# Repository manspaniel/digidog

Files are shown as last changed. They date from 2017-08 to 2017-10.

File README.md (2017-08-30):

# Digi-Dog

Lil digital dog for your pocket, for when you can't have a real dog (or when your real dog doesn't fit in your pocket).

## Work in Progress!

This project isn't finished yet! There's still plenty to do, but the basics are all there.

## PCB Files

Eagle files are provided in the `pcb` folder. I print the circuit board layout onto transparent A4 overhead projector material, then use pre-sensitised PCB boards + developer + chemical etchant to produce the boards. Watch [this video](https://www.youtube.com/watch?v=tWnfnt2rNO0) for the process I follow. It's easy once you have the stuff :)

This is my first PCB design. The layout is a bit shit, but that's ok.

## Uploading

I'm using Platform IO to manage platforms/libraries, and to upload compiled code to the ATTiny85. To program the chip, I'm using [https://www.sparkfun.com/products/11801](SparkFun Tiny Programmer), which is just great; you can program on the chip, or use breakout wires to program onto your soldered prototype. (I've added a breakout header row to my PCB for connecting the microcontroller to the programmer via some breadboard jumper wires).

## Tools

Comes with a custom-made sprite drawing program. To use:

```bash
> cd tools/sprite-draw
> npm install
> npm start
```

Documentation for the sprite drawing tool is [here](./tools/sprite-draw/README.md).

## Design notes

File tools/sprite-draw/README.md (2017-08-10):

Dog Editor
==========

A quick and hacky tile-based bitmap editor, specifically built for the purpose
of creating virtual pet dog sprites and related imagery.

## Running the tool

You'll need Node JS 8 or higher installed for this tool to work.

After you've cloned the project repository, cd into the dog editor folder, and start her up!

```bash
> cd tools/dog-editor
> npm install
> npm start
```

## Tile system

The system uses a tile system.

A **tileset** is a group of 64 tiles. Tilesets are all stored together, however they are paged in chunks of 64 to reduce the size of the sprites themselves, while expanding the amount of tiles that can be used by the program.

A **tiles** is an 8x8 monochrome bitmap. Each column (or row) can be represented in 1 byte (8 bits), since there are only two possible values for each pixel — black or white. This means each tile takes up 8 bytes in total.

A **sprite** (probably poorly named) has a variable width and height, and is composed entirely of tiles. A sprite must also reference a single **tileset**, which means that no sprite can use tiles from two different tilesets.

Tilesets are in groups of 64, because it means that each tile within a sprite can be referenced with only one byte. Two bits of each sprite tile each is reserved for flipX and flipY, and the remaining 6 bits can be used to reference a tile. The tileset number attached to the sprite just provides the pagination value.

## Loading and Saving

Hit the "Save" button to persist your tiles and sprites to disk.

Hit the "Reload" button to reload the persisted data.

Hit the "Publish Headers" button to generate and publish the `tiles.h` file to the parent project (ie. `../../src/tiles.h`).

## Persisting to a different file

All data is persisted in a JSON file, which by default is `data.json` within the dog-editor project folder. When booting the server app, you can actually specify another file using:

```bash
> npm start -- doggytest.json
```

## Tips and Functions

In the "Tiles" section:

* Drag with the mouse from one tile to another to copy sprite data!
* Do the same while holding SHIFT to *swap* those tiles. Sprites using either of those tiles will also be updated to point to the swapped tile, so your tiles wont break. This is really useful for organising your tileset.
* Clicking on a tile will highlight in green any sprite which uses that tile. This is good for determining if a tile is actually in use by any sprite.

In the sprite editor:

* Tools are represented by letters. You can press that letter on your keyboard to activate the tool!
* Some tools do something different when you right click.
  * The pencil tool (P) draws white by default, and erases to black with right mouse button.
  * The tile tool (T) draws the selected tile, but if you right click on a tile in your active sprite it acts as an eye dropper!

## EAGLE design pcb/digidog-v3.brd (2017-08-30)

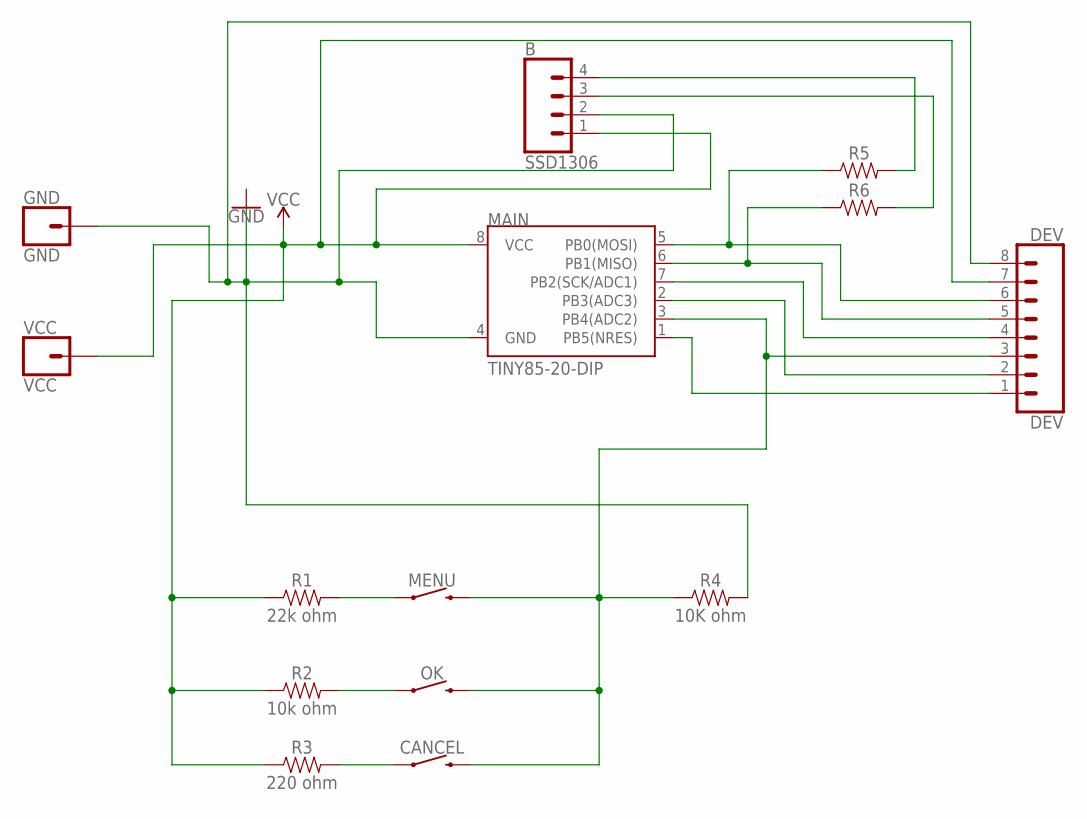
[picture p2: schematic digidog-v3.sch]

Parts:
B: SSD1306; 1X04
CANCEL: MOMENTARY-SWITCH-SPST-PTH-6.0MM; TACTILE_SWITCH_PTH_6.0MM
DEV: DEV; 1X08
GND: GND; 1X01
MAIN: TINY85-20-DIP; DIP08_MCU
MENU: MOMENTARY-SWITCH-SPST-PTH-6.0MM; TACTILE_SWITCH_PTH_6.0MM
OK: MOMENTARY-SWITCH-SPST-PTH-6.0MM; TACTILE_SWITCH_PTH_6.0MM
R1: 22k ohm; AXIAL-0.3
R2: 10k ohm; AXIAL-0.3
R3: 220 ohm; AXIAL-0.3
R4: 10K ohm; AXIAL-0.3
R5, R6: AXIAL-0.3
VCC: VCC; 1X01

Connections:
BUTTON: CANCEL.3 (2), DEV.3, MAIN.3 (PB4(ADC2)), MENU.3 (2), OK.3 (2), R4.P$1 (1)
GND: B.2, DEV.8, GND.1, MAIN.4 (GND), R4.P$2 (2)
unnamed: B.4, R5.P$2 (2)
unnamed: MENU.1, R1.P$2 (2)
unnamed: OK.1, R2.P$2 (2)
unnamed: CANCEL.1, R3.P$2 (2)
unnamed: DEV.6, MAIN.5 (PB0(MOSI)), R5.P$1 (1)
unnamed: DEV.5, MAIN.6 (PB1(MISO)), R6.P$1 (1)
unnamed: B.3, R6.P$2 (2)
unnamed: DEV.1, MAIN.1 (PB5(NRES))
unnamed: DEV.2, MAIN.2 (PB3(ADC3))
unnamed: DEV.4, MAIN.7 (PB2(SCK/ADC1))
VCC: B.1, DEV.7, MAIN.8 (VCC), R1.P$1 (1), R2.P$1 (1), R3.P$1 (1), VCC.1

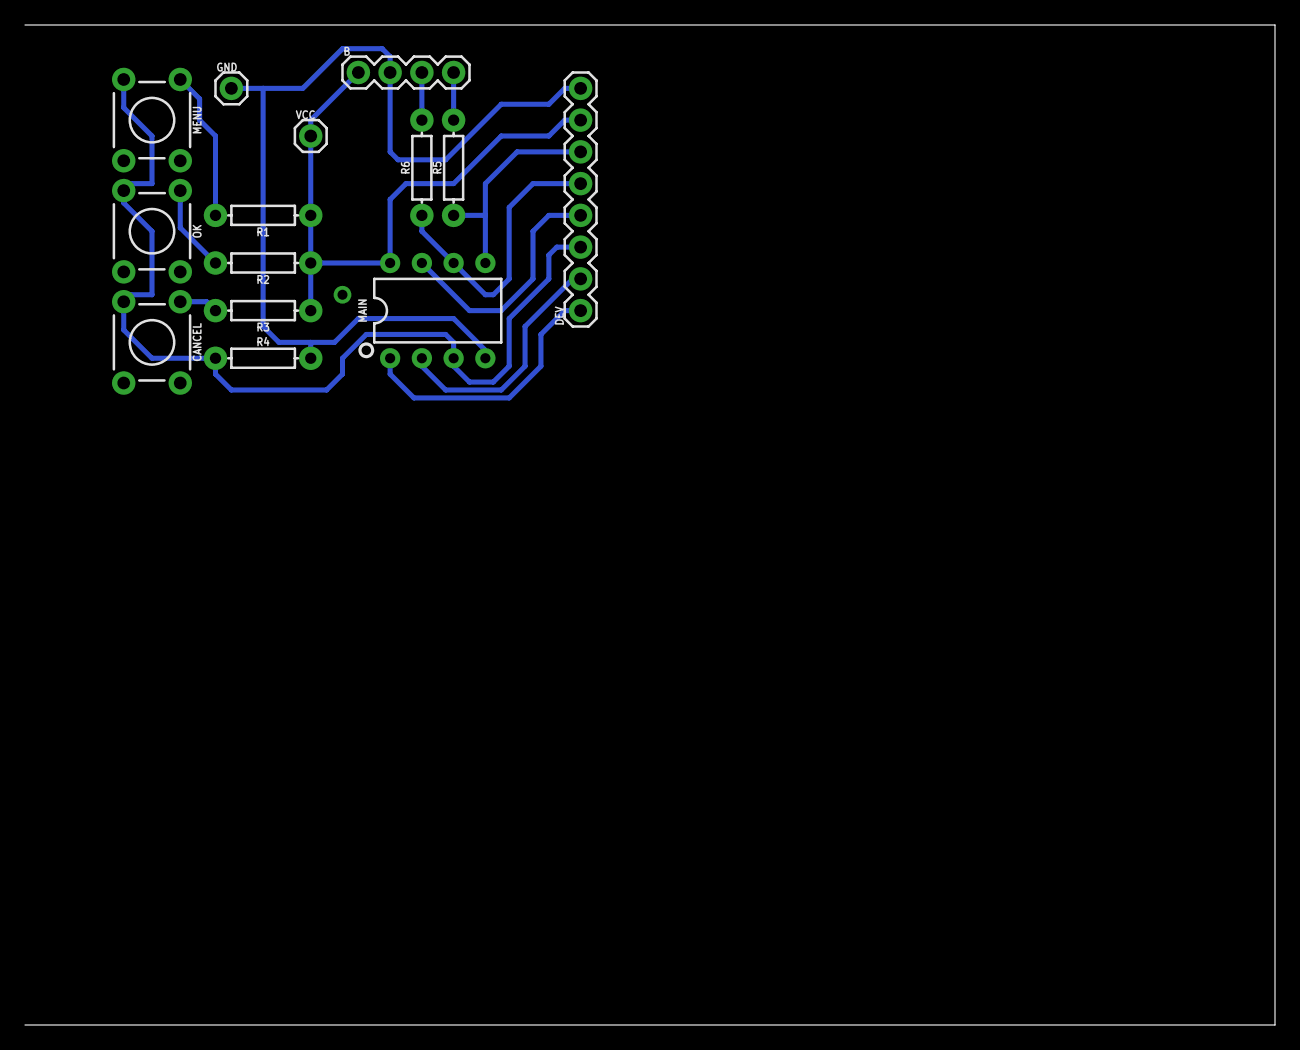
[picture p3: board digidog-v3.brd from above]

Board: 2 copper layers, 100.0 x 80.0 mm, 14 parts (0 on the bottom side), 13 nets.

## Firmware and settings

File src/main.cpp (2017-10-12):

#include <Arduino.h>
// #define F_CPU 8000000UL      //ATtiny85 CPU Clock speed (8MHz optimal[8000000], 1MHz Default[1000000])

#define SSD1306_SA    0x78  // Slave address

// #include <stdlib.h>
// #include <avr/io.h>
// #include <util/delay.h>
// #include <avr/pgmspace.h>
// #include <avr/sleep.h>

#include "ssd1306xled.h"
#include "DigiDog.h"
#include "SpriteDisplay.h"

// void * operator new(size_t size) {
//   return malloc(size);
// }
//
// void operator delete(void * ptr) {
//   free(ptr);
// }

// #define CALIBRATON_MODE true

#ifndef CALIBRATON_MODE
  SpriteDisplay mainDisplay;
  DigiDog doggy;
#endif

void setup() {
  // Small delay is necessary if ssd1306_initis the first operation in the application.
  // _delay_ms(40);
  ssd1306_init();
 
  ssd1306_fillscreen(0x0);
  // ssd1306_char_f8x16(1, 2, "VDOG");
  delay(100);
 
  // set_sleep_mode(SLEEP_MODE_PWR_DOWN);
  // setup_watchdog(6);
 
  // uint8_t p = 0xff;
 
  // for (uint8_t i = 0; i < 4; i++) {
  //   p = (p >> i);
  //   ssd1306_fillscreen(~p);
  //   _delay_ms(200);
  // }
  
  // pinMode(A2, INPUT);
  
  #ifndef CALIBRATON_MODE
    doggy.start();
  #endif
  
}

void loop() {
  
  // Figure out the current button
  
  #ifdef CALIBRATON_MODE
    int signal = analogRead(A2);
    
    ssd1306_fill_range(0, 60, 0x00);
    char buffer[10];         //the ASCII of the integer will be stored in this char array
    itoa(signal, buffer, 10);
    ssd1306_char_f6x8(0, 0, buffer);
  #endif
  
  #ifndef CALIBRATON_MODE
    doggy.loop();
  #endif
  
  // delay(100);
  
  // watchdog_counter = analogRead(A2);
  //
  // ssd1306_fill_range(0, 60, 0x00);
  // char buffer[10];         //the ASCII of the integer will be stored in this char array
  // itoa(val, buffer, 10);
  // ssd1306_char_f6x8(0, 0, buffer);
  
  // setup_watchdog(8);
  // sleep_mode();
  
  
  
  // ssd1306_send_byte(252);
 
  // ssd1306_char_f6x8(1, 0, "Who says I can't run this LED screen?");
  // _delay_ms(5000);
  //
  //
  // ssd1306_char_f6x8(1, 0, "There am I running it now.");
  // _delay_ms(5000);
 
}

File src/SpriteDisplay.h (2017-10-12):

#ifndef SPRITE_DISPLAYM_H
#define SPRITE_DISPLAYM_H

#include <stdlib.h>
#include <avr/io.h>
#include <avr/pgmspace.h>
#include "ssd1306xled.h"
#include "tiles.h"
#include "font6x8.h"

#define MAX_SPRITES               16
#define SPRITE_HEADER_SIZE        3

class SpriteDisplay;

struct Sprite {
  const uint8_t * data;
  bool active = false;
  uint8_t tileset = 0;
  uint8_t x = 0;
  uint8_t y = 0;
  uint8_t width = 0;
  uint8_t height = 0;
  char cols = 0;
  char rows = 0;
  
  uint8_t lastX = 0;
  uint8_t lastY = 0;
  uint8_t lastWidth = 0;
  uint8_t lastHeight = 0;
  
  bool hasRendered = false;
  bool needsUpdate = false;
};

class SpriteDisplay {
public:
  Sprite sprites[MAX_SPRITES];
  uint32_t dirtyCells[8];
  
  const uint8_t * tileset;
  
  SpriteDisplay();
  Sprite * addSprite (const uint8_t * spriteData);
  bool rectsOverlap (int x1, int y1, int w1, int h1, int x2, int y2, int w2, int h2);
  uint8_t getTileByte(Sprite * sprite, uint8_t x, uint8_t y, uint8_t shiftX, bool alpha);
  void setDirtyRect (uint8_t x, uint8_t y, uint8_t w, uint8_t h);
  void update ();
  void removeAllSprites ();
  void wipe ();
  void writeText(uint8_t x, uint8_t y, const char * str);
};

#endif

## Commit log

2017-08-30 Added eagle, changes to dog editor
    [digidog-v3.brd, digidog-v3.sch]
2017-09-03 Fixed bug with resizing sprites in editor. Fixed overdraw bug
    [SpriteDisplay.h]
2017-09-03 Dirtying screen segments now aligns correctly
    [SpriteDisplay.h]
2017-10-12 Fixed init ram issue, added basic menu
    [SpriteDisplay.h]

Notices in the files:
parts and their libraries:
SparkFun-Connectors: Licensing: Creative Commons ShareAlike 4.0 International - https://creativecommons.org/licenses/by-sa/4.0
